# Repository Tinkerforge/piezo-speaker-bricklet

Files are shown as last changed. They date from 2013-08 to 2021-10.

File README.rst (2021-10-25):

Piezo Speaker Bricklet
======================

This repository contains the firmware source code and the hardware design
files. The documentation generator configs can be found at
https://github.com/Tinkerforge/generators

Repository Content
------------------

software/:
 * examples/: Examples for all supported languages
 * build/: Compiled files
 * src/: Source code of firmware
 * Makefile: Makefile to build project

hardware/:
 * Contains KiCad project files and additionally schematics as PDF

datasheets/:
 * Contains datasheets for sensors and complex ICs that are used

Hardware
--------

The hardware is designed with the open source EDA Suite KiCad
(http://www.kicad.org). Before you are able to open the files,
you have to install the Tinkerforge kicad-libraries
(https://github.com/Tinkerforge/kicad-libraries). You can either clone
them directly in hardware/ or clone them in a separate folder and
symlink them into hardware/
(ln -s kicad_path/kicad-libraries project_path/hardware). After that you
can open the .pro file in hardware/ with KiCad and from there view and
modify the schematics and the PCB layout.

Software
--------

If you want to do your own Brick/Bricklet firmware development we highly
recommend that you use our build environment setup script and read the
tutorial (https://www.tinkerforge.com/en/doc/Tutorials/Tutorial_Build_Environment/Tutorial.html).

To compile the C code we recommend you to install the newest GNU Arm Embedded
Toolchain (https://launchpad.net/gcc-arm-embedded/+download).
You also need to install bricklib (https://github.com/Tinkerforge/bricklib)
and brickletlib (https://github.com/Tinkerforge/brickletlib).

You can either clone it directly in software/src/ or clone it in a
separate folder and symlink it into software/src/
(ln -s bricklib_path/bricklib project_path/software/src/ and
ln -s brickletlib_path/brickletlib project_path/software/src/).
Finally make sure to have CMake installed
(http://www.cmake.org/cmake/resources/software.html).

After that you can build the firmware by invoking make in software/.
The firmware (.bin) can then be found in software/build/ and uploaded
with brickv (click button "Flashing" on start screen).

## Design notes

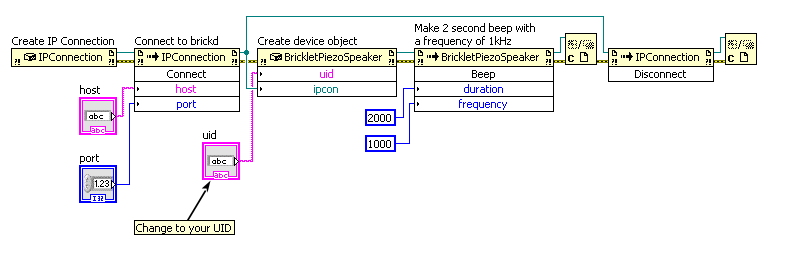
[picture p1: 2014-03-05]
software/examples/labview/Example Beep.vi.png

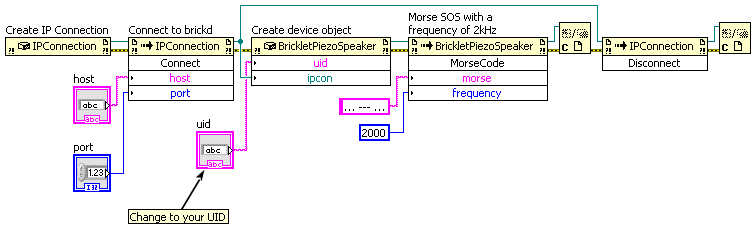
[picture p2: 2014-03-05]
software/examples/labview/Example Morse Code.vi.png

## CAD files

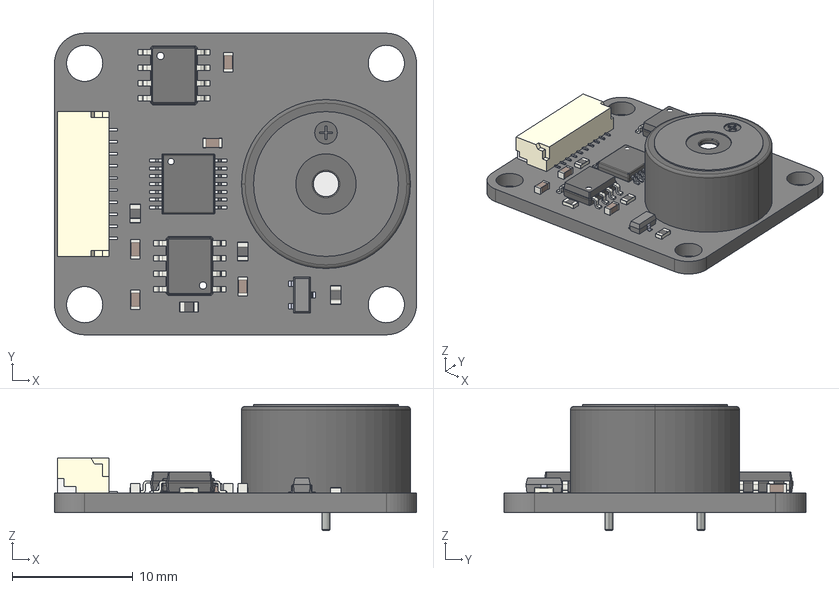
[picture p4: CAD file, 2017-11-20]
hardware/piezo-speaker.step
30.0 x 25.0 x 10.5 mm

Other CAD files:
hardware/piezo-speaker.FCStd

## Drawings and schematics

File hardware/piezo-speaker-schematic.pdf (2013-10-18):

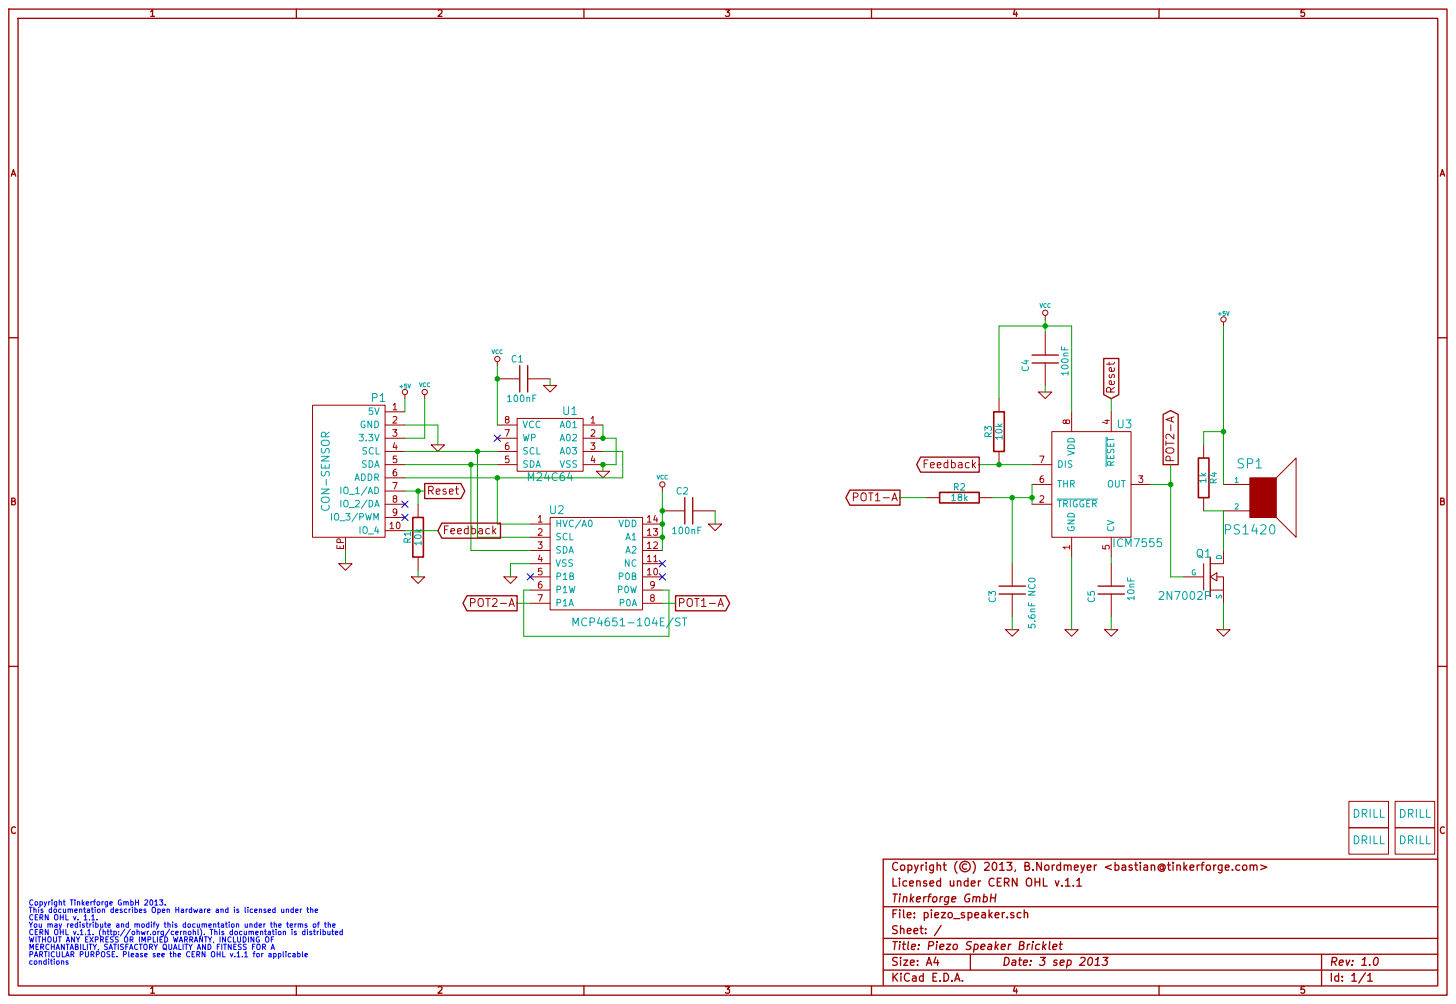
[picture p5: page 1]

VCC Copyright Tinkerforge GmbH 2013. This documentation describes Open Hardware and is licensed under the CERN OHL v. 1.1. You may redistribute and modify this documentation under the terms of the CERN OHL v.1.1. (http://ohwr.org/cernohl). This documentation is distributed WITHOUT ANY EXPRESS OR IMPLIED WARRANTY, INCLUDING OF MERCHANTABILITY, SATISFACTORY QUALITY AND FITNESS FOR A

Copyright (©) 2013, B.Nordmeyer <bastian@tinkerforge.com>
Licensed under CERN OHL v.1.1
Tinkerforge GmbH
File: piezo_speaker.sch
Sheet: /
Title: Piezo Speaker Bricklet
KiCad E.D.A.

PARTICULAR PURPOSE. Please see the CERN OHL v.1.1 for applicable

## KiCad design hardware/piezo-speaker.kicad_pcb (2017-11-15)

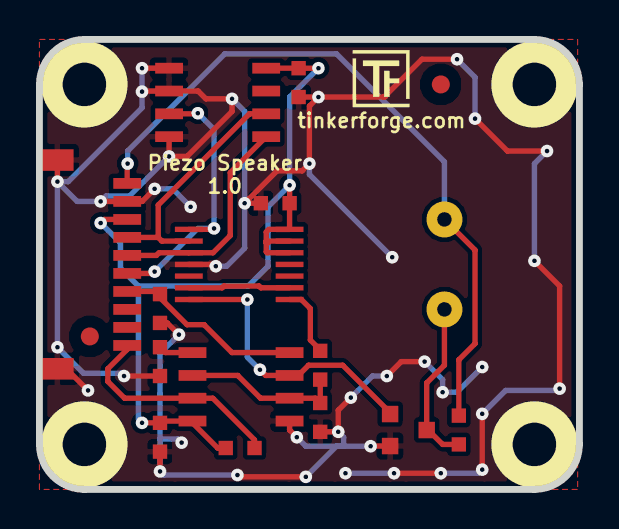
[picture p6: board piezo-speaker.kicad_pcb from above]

Board: 2 copper layers, 30.0 x 25.0 mm, 23 parts (0 on the bottom side), 14 nets.

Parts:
C1, C2, C4: 100nF; C0603
C3: 5.6nF NC0; C0603
C5: 10nF; C0603
Fiducial_Mark: VAL**; Fiducial_Mark
Fiducial_Mark#2: VAL**; Fiducial_Mark
P1: CON-SENSOR
Q1: 2N7002P; SOT23GDS
R1, R3: 10k; R0603
R2: 18k; R0603
R4: 1k; R0603
SP1: PS1420
U1: M24C64; SOIC8
U2: MCP4651-104E/ST; TSSOP14
U3: ICM7555; SOIC8
U4, U5, U6, U7: DRILL; DRILL_NP
VAL: WEEE_7mm
VAL#2: CE_5mm

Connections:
+5V: P1.1, R4.1, SP1.1
Feedback: P1.10, R3.2, U3.7
GND: C1.2, C2.2, C3.1, C4.1, C5.1, P1.2, P1.EP, Q1.S, R1.2, U1.1, U1.2, U1.4, U2.4, U3.1
unnamed: C3.2, R2.2, U3.2, U3.6
unnamed: C5.2, U3.5
unnamed: P1.4, U1.6, U2.2
unnamed: P1.5, U1.5, U2.3
unnamed: P1.6, U1.3, U2.1
unnamed: Q1.D, R4.2, SP1.2
unnamed: U2.6, U2.9
POT1-A: R2.1, U2.8
POT2-A: Q1.G, U2.7, U3.3
Reset: P1.7, R1.1, U3.4
VCC: C1.1, C2.1, C4.2, P1.3, R3.1, U1.8, U2.12, U2.13, U2.14, U3.8

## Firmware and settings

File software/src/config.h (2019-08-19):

/* piezo-speaker-bricklet
 * Copyright (C) 2013 Olaf Lüke <olaf@tinkerforge.com>
 * Copyright (C) 2014 Matthias Bolte <matthias@tinkerforge.com>
 *
 * config.h: Piezo Speaker Bricklet specific configuration
 *
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
 * You should have received a copy of the GNU Lesser General Public
 * License along with this library; if not, write to the
 * Free Software Foundation, Inc., 59 Temple Place - Suite 330,
 * Boston, MA 02111-1307, USA.
 */

#ifndef CONFIG_H
#define CONFIG_H

#include <stdint.h>
#include <stdbool.h>

#include "bricklib/drivers/board/sam3s/SAM3S.h"

#include "piezo-speaker.h"

#define BRICKLET_FIRMWARE_VERSION_MAJOR 2
#define BRICKLET_FIRMWARE_VERSION_MINOR 0
#define BRICKLET_FIRMWARE_VERSION_REVISION 3

#define BRICKLET_HARDWARE_VERSION_MAJOR 1
#define BRICKLET_HARDWARE_VERSION_MINOR 0
#define BRICKLET_HARDWARE_VERSION_REVISION 0

#define BRICKLET_DEVICE_IDENTIFIER 242

#define BOARD_MCK 64000000
#define INVOCATION_IN_BRICKLET_CODE

#define PIN_ENABLE   (BS->pin1_ad)
#define PIN_FEEDBACK (BS->pin4_io)
#define MAX_MORSE_LENGTH 60
#define CALIBRATION_LENGTH 65

typedef struct {
	uint32_t beep_duration;
	uint32_t morse_duration;
	char morse[MAX_MORSE_LENGTH];
	bool morse_buzz;
	uint8_t morse_pos;

	uint8_t morse_length;

	bool beep_finished;
	bool morse_finished;

	uint16_t frequency_match[CALIBRATION_LENGTH];
} BrickContext;

#endif

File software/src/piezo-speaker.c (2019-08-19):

/* piezo-speaker-bricklet
 * Copyright (C) 2013 Olaf Lüke <olaf@tinkerforge.com>
 * Copyright (C) 2014 Matthias Bolte <matthias@tinkerforge.com>
 *
 * piezo-speaker.c: Implementation of Piezo Speaker Bricklet message
 *
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
 * You should have received a copy of the GNU Lesser General Public
 * License along with this library; if not, write to the
 * Free Software Foundation, Inc., 59 Temple Place - Suite 330,
 * Boston, MA 02111-1307, USA.
 */

#include "piezo-speaker.h"

#include "brickletlib/bricklet_entry.h"
#include "bricklib/bricklet/bricklet_communication.h"
#include "bricklib/com/i2c/i2c_eeprom/i2c_eeprom_common.h"
#include "bricklib/drivers/adc/adc.h"
#include "config.h"
#include "bricklib/utility/util_definitions.h"
#include "bricklib/utility/init.h"

#define MORSE_DIT_LENGTH   100
#define MORSE_DAH_LENGTH   (MORSE_DIT_LENGTH*3)
#define MORSE_SPACE_LENGTH MORSE_DIT_LENGTH

#define BEEP_DURATION_OFF      0
#define BEEP_DURATION_INFINITE UINT32_MAX

void invocation(const ComType com, const uint8_t *data) {
	switch(((MessageHeader*)data)->fid) {
		case FID_BEEP: {
			beep(com, (Beep*)data);
			break;
		}

		case FID_MORSE_CODE: {
			morse_code(com, (MorseCode*)data);
			break;
		}

		case FID_CALIBRATE: {
			calibrate(com, (Calibrate*)data);
			break;
		}

		default: {
			BA->com_return_error(data, sizeof(MessageHeader), MESSAGE_ERROR_CODE_NOT_SUPPORTED, com);
			break;
		}
	}
}

uint8_t get_i2c_address(void) {
	if(BS->address == I2C_EEPROM_ADDRESS_HIGH) {
		return I2C_ADDRESS_HIGH;
	} else {
		return I2C_ADDRESS_LOW;
	}
}

uint16_t frequency_to_frequency_value(uint16_t frequency) {
	uint16_t distance = 0xFFFF;
	uint16_t best_match = 0;
	for(uint8_t i = 0; i < CALIBRATION_LENGTH; i++) {
		uint16_t new_distance = ABS(BC->frequency_match[i]-frequency);
		if(new_distance < distance) {
			distance = new_distance;
			best_match = i;
		}
	}

	if(best_match == 0) {
		return 0;
	}

	if(best_match == 64) {
		return 512;
	}

	int8_t add = 0;
	if(frequency < BC->frequency_match[best_match]) {
		add = -7 + SCALE(frequency, BC->frequency_match[best_match-1], BC->frequency_match[best_match], 0, 7);
	} else {
		add = SCALE(frequency, BC->frequency_match[best_match], BC->frequency_match[best_match+1], 0, 7);
	}

	return best_match*8 + add;
}

void set_frequency(uint16_t frequency) {
	frequency = MIN(frequency, FREQUENCY_VALUE_SUM_MAX);
	uint16_t value1 = frequency;
	uint16_t value2 = 0;

	if(frequency > FREQUENCY_VALUE_MAX) {
		value1 = FREQUENCY_VALUE_MAX;
		value2 = frequency - FREQUENCY_VALUE_MAX;
	}

	const uint8_t command_bit1 = value1 & (1 << 8) ? 1 : 0;
	const uint8_t command_bit2 = value2 & (1 << 8) ? 1 : 0;

	uint8_t data[3];
	data[0] = value1 & 0xFF;
	data[1] = I2C_COMMAND_WIPER1 | I2C_ACTION_WRITE | command_bit2;

	data[2] = value2 & 0xFF;

	if(BA->mutex_take(*BA->mutex_twi_bricklet, 10)) {
		BA->bricklet_select(BS->port - 'a');
		BA->TWID_Write(BA->twid,
		               get_i2c_address(),
					   I2C_COMMAND_WIPER0 | I2C_ACTION_WRITE | command_bit1,
					   1,
					   data,
					   3,
					   (Async*)NULL);
		BA->bricklet_deselect(BS->port - 'a');
		BA->mutex_give(*BA->mutex_twi_bricklet);
	}
}

void constructor(void) {
	_Static_assert(sizeof(BrickContext) <= BRICKLET_CONTEXT_MAX_SIZE, "BrickContext too big");

	PIN_ENABLE.type = PIO_OUTPUT_0;
	PIN_ENABLE.attribute = PIO_DEFAULT;
    BA->PIO_Configure(&PIN_ENABLE, 1);

    PIN_FEEDBACK.type = PIO_INPUT;
    PIN_FEEDBACK.attribute = PIO_DEFAULT;
    BA->PIO_Configure(&PIN_FEEDBACK, 1);

    BC->morse_pos = 60;
    BC->morse_duration = 0;
    BC->morse_buzz = false;
    BC->beep_duration = BEEP_DURATION_OFF;
    BC->morse_length = 0;

    load_calibration();
}

void destructor(void) {
	PIN_ENABLE.type = PIO_INPUT;
	PIN_ENABLE.attribute = PIO_PULLUP;
    BA->PIO_Configure(&PIN_ENABLE, 1);

    PIN_FEEDBACK.type = PIO_INPUT;
    PIN_FEEDBACK.attribute = PIO_PULLUP;
    BA->PIO_Configure(&PIN_FEEDBACK, 1);
}

void beep(const ComType com, const Beep *data) {
	// Disable morse code beeping
	BC->morse_pos = MAX_MORSE_LENGTH;
	BC->morse_duration = 0;
	BC->morse_buzz = false;

	// Only set frequency if there will be a beep
	if(data->duration != BEEP_DURATION_OFF) {
		set_frequency(frequency_to_frequency_value(data->frequency));
	}

	// Disable beep if it's currently on, but should be off
	if(BC->beep_duration != BEEP_DURATION_OFF && data->duration == BEEP_DURATION_OFF) {
		PIN_ENABLE.pio->PIO_CODR = PIN_ENABLE.mask;
	}

	BC->beep_duration = data->duration;

	// Enable beep if it should be on
	if(BC->beep_duration != BEEP_DURATION_OFF) {
		PIN_ENABLE.pio->PIO_SODR = PIN_ENABLE.mask;
	}

	BA->com_return_setter(com, data);
}

void morse_code(const ComType com, const MorseCode *data) {
	// Disable beep
	BC->beep_duration = BEEP_DURATION_OFF;

	// Enable morse code beeping
	BC->morse_pos = 0;
	BC->morse_duration = 0;
	BC->morse_buzz = false;

	uint8_t i = 0;
	for(; i < MAX_MORSE_LENGTH; i++) {
		if(data->morse[i] != '.' && data->morse[i] != '-' && data->morse[i] != ' ') {
			break;
		}

		BC->morse[i] = data->morse[i];
	}

	BC->morse_length = i+1;
	set_frequency(frequency_to_frequency_value(data->frequency));

	BA->com_return_setter(com, data);
}

void load_calibration(void) {
    BA->bricklet_select(BS->port - 'a');
    BA->i2c_eeprom_master_read(BA->twid->pTwi,
                               EEPROM_CALIBRATION_POSITION,
                               (char *)BC->frequency_match,
                               EEPROM_CALIBRATION_LENGTH*2);
    BA->bricklet_deselect(BS->port - 'a');
}

void save_calibration(void) {
	// Save calibration in 32 byte chunks
    BA->bricklet_select(BS->port - 'a');
    BA->i2c_eeprom_master_write(BA->twid->pTwi,
                                EEPROM_CALIBRATION_POSITION,
                                (char *)BC->frequency_match,
                                32);
    BA->i2c_eeprom_master_write(BA->twid->pTwi,
                                EEPROM_CALIBRATION_POSITION+32,
                                (char *)BC->frequency_match+32,
                                32);
    BA->i2c_eeprom_master_write(BA->twid->pTwi,
                                EEPROM_CALIBRATION_POSITION+64,
                                (char *)BC->frequency_match+64,
                                32);
    BA->i2c_eeprom_master_write(BA->twid->pTwi,
                                EEPROM_CALIBRATION_POSITION+96,
                                (char *)BC->frequency_match+96,
                                32);
    BA->i2c_eeprom_master_write(BA->twid->pTwi,
                                EEPROM_CALIBRATION_POSITION+128,
                                (char *)BC->frequency_match+128,
                                2);
    BA->bricklet_deselect(BS->port - 'a');
}
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

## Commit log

2013-08-30 value to frquency graph for new capacitor and resistor values
2013-09-04 Add frequency calibration function
2013-10-15 add hardware files
    [piezo_speaker.kicad_pcb, piezo_speaker.sch]
2013-10-18 add missing schematic
2014-04-02 perl: Unify print style
2015-08-07 Use full device class name in Python examples
2016-05-18 c: Add missing device destroy call
2017-11-15 Add 3d information
    [piezo_speaker.kicad_pcb, piezo_speaker.sch]
2017-11-15 Fix edge cuts
    [piezo_speaker.kicad_pcb]
2017-11-20 Add 3d model (*.step & *.FCStd)
    [piezo_speaker.FCStd, piezo_speaker.step]
2018-02-20 Cleanup KiCad libraries config
    Ensure LibDir=kicad-libraries and LibName1=tinkerforge.
    Remove special library.
2018-05-11 Rename files
    [piezo-speaker.FCStd, piezo-speaker.kicad_pcb, piezo-speaker.sch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]
2019-08-19 Don't disable IRQs during calibration
    Mewer Brick versions use interrupts during I2C communication
2021-10-25 Update KiCad link
    https://www.kicad.org/blog/2021/10/Avoid-links-to-former-kicad-domain/
